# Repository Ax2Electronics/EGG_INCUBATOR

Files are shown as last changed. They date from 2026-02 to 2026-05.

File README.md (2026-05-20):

# EGG_INCUBATOR
Egg Incubator Chamber With Custom Made Modern Controller Interface, quality and accuracy oriented.

BLOCK DIAGRAM of Incubation Controller
PDF: [INCUBATION_CONTROLLER_BD_V7.pdf](https://github.com/user-attachments/files/28039047/INCUBATION_CONTROLLER_BD_V7.pdf)



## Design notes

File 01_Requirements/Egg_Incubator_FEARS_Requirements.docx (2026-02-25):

PRODUCT REQUIREMENTS SPECIFICATION

Chicken Egg Incubator Controller | FEARS Format | Version 1.0 | DRAFT

Document Title | Product Requirements Specification – Chicken Egg Incubator Controller
Product | Fully Automatic Egg Incubator (up to 100 eggs)
Format | FEARS (Functional / Electrical & Environmental / Appearance & Aesthetic / Regulatory & Reliability / Safety & Standards)
Target Market | Balkan Region (Serbia primary) and EU
Document Version | 1.0 – Draft for Review
Date | 25 February 2026
Prepared By | Requirements Engineering Team (Electronics, Firmware, Mechanical, Regulatory)
Status | DRAFT – Pending technical and regulatory review

# 1. Introduction & Scope

This document defines the complete product requirements for a Fully Automatic Chicken Egg Incubator Controller in FEARS format. Requirements cover the full product lifecycle from manufacturing, first use, normal operation, edge and misuse conditions, maintenance, and end-of-life decommissioning. All requirements are written to support CE marking for the EU market and Serbian market compliance.

Priority notation: Must = mandatory requirement; Should = strongly recommended; May = optional / nice to have.

# F | FUNCTIONAL REQUIREMENTS

ID | Sub-System / Feature | Requirement Statement | Priority | Use Case / Context
F-001 | Temperature Control | The system SHALL maintain egg chamber temperature in range 37.0°C – 39.0°C with a steady-state accuracy of ±0.1°C. | Must | Normal, First Use
F-002 | Temperature Sensing | The system SHALL use a minimum of 2 independent temperature sensors (NTC/PT100) with cross-validation. If sensors disagree by >0.5°C, alarm shall be raised. | Must | Normal, Fault
F-003 | Humidity Control | The system SHALL control relative humidity (RH) in the range 40%–80% RH ±3% RH via automatic water dispensing from external tank. | Must | Normal
F-004 | Humidity Sensing | The system SHALL measure humidity using a digital RH/T sensor (e.g., SHT3x class). Sensor shall be recalibrated or cross-checked at each power-on. | Must | Normal, Startup
F-005 | Water Level Monitoring | The system SHALL monitor the water tank level. An alert SHALL be displayed and audible alarm triggered when tank drops below minimum level. | Must | Normal, Depletion
F-006 | Fan Operation | The system SHALL operate an internal circulation fan continuously during incubation to ensure uniform temperature distribution (≤±0.3°C variation chamber-wide). | Must | Normal
F-007 | Fan Fault Detection | The system SHALL detect fan failure (stall or over-current) within 30 seconds and raise an audible + visual alarm. | Must | Fault
F-008 | Egg Turning – Auto | The system SHALL automatically turn eggs at configurable intervals (default: every 2h ±5 min) through the turning mechanism, stopping 3 days before projected hatch. | Must | Normal
F-009 | Egg Turning – Manual Override | The operator SHALL be able to manually trigger an egg turn from the touchscreen at any time outside the lockdown period. | Should | Manual Operation
F-010 | Lockdown Mode | The system SHALL enter a 'Lockdown' mode in the last 3 days of incubation, stopping egg turning and adjusting humidity to 65%–70% RH automatically. | Must | Hatch Phase
F-011 | Incubation Timer | The system SHALL track incubation day count from a user-set start date. Countdown to expected hatch date shall be displayed. | Must | Normal
F-012 | LED Lighting | The system SHALL provide internal LED illumination, controllable via touchscreen (ON/OFF + brightness). LED SHALL automatically extinguish when door is opened. | Must | Normal, Door Open
F-013 | Touchscreen Display | The system SHALL present real-time readings (temperature, humidity, fan status, water level, incubation day, alarms) on an LCD touchscreen ≥3.5 inches diagonal. | Must | Normal
F-014 | Alarm System | The system SHALL provide audible (≥70 dB @ 1m) and visual alarms for: high/low temperature, high/low humidity, fan failure, water low, power failure, sensor fault. | Must | Fault, Emergency
F-015 | Alarm Mute / Acknowledge | The user SHALL be able to acknowledge/mute alarms via touchscreen. Alarm condition shall be logged even if muted. Mute SHALL auto-expire after 60 minutes. | Must | Fault
F-016 | Power Failure Handling | Upon power loss, the system SHALL retain all settings, alarm history, and incubation timer data in non-volatile memory (EEPROM/Flash). Upon restore, it SHALL resume operation automatically. | Must | Power Failure
F-017 | Configurable Parameters | The operator SHALL be able to set target temperature, target humidity, turning interval, incubation duration, and alarm thresholds via the touchscreen menu. | Must | Setup
F-018 | Factory Default Reset | The system SHALL provide a factory default reset function, accessible only through a multi-step confirmation on the touchscreen to prevent accidental reset. | Must | Setup, Edge Case
F-019 | Heater Safety Cutoff | The system SHALL automatically disable all heaters if measured temperature exceeds 41.0°C (hard safety limit), regardless of software state. | Must | Safety, Fault
F-020 | Self-Test on Power-Up | On each power-up, the system SHALL perform a self-test of sensors, heater, fan, and display, reporting results to the user before entering normal operation. | Must | Startup
F-021 | Data Logging | The system SHOULD log temperature, humidity, alarm events and operator actions with timestamp, accessible via touchscreen log view (minimum 30-day retention). | Should | Normal, Audit
F-022 | Child/Tamper Lock | The system SHALL provide a touchscreen lock function to prevent unintended parameter changes during active incubation. | Should | Edge Case, Misuse Prevention
F-023 | Egg Capacity Indication | The system SHALL support up to 100 chicken eggs. Firmware SHALL NOT constrain egg count but documentation shall state maximum safe load. | Must | Normal
F-024 | Language Support | The HMI (touchscreen) SHALL support at minimum English, Serbian, Croatian, and Romanian language settings. | Should | Balkan Market
F-025 | Firmware Update | The system SHOULD support secure firmware updates via USB or SD card with integrity verification (CRC/hash check) and rollback capability. | Should | Lifecycle, Maintenance

# E | ELECTRICAL & ENVIRONMENTAL REQUIREMENTS

ID | Parameter | Requirement Statement | Priority | Context
E-001 | Supply Voltage | The device SHALL operate from 230V AC ±10%, 50 Hz mains supply (Balkan/EU standard). | Must | Normal
E-002 | Power Consumption | Total system power consumption at full load (all heaters, fan, lights, controls) SHALL not exceed 200W. | Must | Normal
E-003 | Mains Fusing | A suitably rated mains fuse (T2A min) SHALL be installed on the line conductor of the mains input, accessible for user replacement. | Must | Safety
E-004 | Protective Earth | All metallic enclosure parts SHALL be connected to protective earth (PE). Earth continuity resistance SHALL be ≤0.1Ω. | Must | Safety, Regulatory
E-005 | Heater Design | Heating elements SHALL be PTC or nichrome type, rated for ≥50,000 operating hours. Watt density SHALL be chosen to prevent surface temperature exceeding 80°C. | Must | Reliability
E-006 | EMC – Emissions | The device SHALL comply with EN 55032 Class B conducted and radiated emission limits for residential/commercial use. | Must | Regulatory
E-007 | EMC – Immunity | The device SHALL comply with EN 55035 immunity requirements. Critical functions (temperature control, alarms) SHALL remain operational during ESD, EFT/Burst, and surge tests. | Must | Regulatory
E-008 | ESD Protection | All user-accessible interfaces (touchscreen, USB/SD card slot) SHALL be protected with TVS diodes to withstand ±4kV contact / ±8kV air ESD (IEC 61000-4-2 Level 2/3). | Must | Robustness
E-009 | Surge Protection | The mains input SHALL include a MOV-based surge protector capable of absorbing 1kV/2kV differential/common mode surges per IEC 61000-4-5. | Must | Robustness
E-010 | Operating Temperature (Electronics) | All electronic components SHALL be rated for continuous operation at ambient temperatures of 0°C to +50°C. | Must | Environmental
E-011 | Storage Temperature | The device SHALL withstand storage at -20°C to +70°C without permanent damage (non-operational). | Must | Lifecycle
E-012 | Humidity (Electronics) | Electronics SHALL be protected against condensation. PCBs SHALL be conformally coated or adequately enclosed. Operating RH for electronics: 20% – 85% non-condensing. | Must | Environmental
E-013 | Ingress Protection – Water System | Components in contact with water (humidity system, tank sensors) SHALL be rated IP54 minimum. Main electronics enclosure: IP22 minimum. | Must | Safety, Environmental
E-014 | Insulation Resistance | Insulation resistance between mains-live conductors and accessible parts SHALL be ≥2MΩ at 500V DC under dry conditions. | Must | Safety
E-015 | Dielectric Strength | The device SHALL withstand a 1500V AC dielectric strength test between primary and secondary circuits for 1 minute without breakdown. | Must | Safety, Regulatory
E-016 | Leakage Current | Touch current (leakage) SHALL not exceed 0.5mA (Class I device, EN 60335 criteria). | Must | Safety
E-017 | Low-Voltage Supply (Internal) | Internal SMPS shall provide galvanically isolated 5V/12V/24V DC rails. Isolation SHALL meet reinforced insulation requirements per IEC 62368 or EN 60335. | Must | Safety
E-018 | Over-Temperature Protection (Heater PCB) | A hardware independent thermal fuse (one-shot, ≤105°C trip) SHALL be physically mounted on or near each heating element as last-resort protection. | Must | Safety
E-019 | Watchdog Timer | Firmware SHALL implement a hardware watchdog timer (≤1s timeout) to recover from software lockup. Safety-critical outputs (heaters) SHALL default to OFF on watchdog reset. | Must | Safety, Reliability
E-020 | Battery Backup (RTC) | A coin cell battery SHALL maintain the real-time clock and incubation timer for a minimum of 5 years (device unused). | Must | Reliability
E-021 | Motor Driver Protection | The egg-turning motor driver SHALL include overcurrent protection, stall detection, and soft-start to prevent mechanical and electrical damage. | Must | Reliability

# A | APPEARANCE & AESTHETIC REQUIREMENTS

ID | Sub-System / Feature | Requirement Statement | Priority | Use Case / Context
A-001 | Enclosure Material | The main enclosure SHALL be constructed from ABS or similar food-safe, non-toxic plastic, resistant to cleaning agents (IPA, dilute bleach). | Must | Lifecycle, Safety
A-002 | Colour and Finish | The exterior SHALL use neutral, easy-to-clean colour (white, light grey or beige). Surface finish shall be matte or satin to minimise fingerprint visibility. | Must | Aesthetics
A-003 | Display Visibility | The LCD touchscreen SHALL be readable in ambient light conditions of 100–1000 lux. Minimum display contrast ratio: 300:1. Text size on main screen ≥ 14pt equivalent. | Must | Usability
A-004 | Viewing Window | The incubation chamber SHALL include a transparent polycarbonate or tempered glass viewing window enabling egg observation without opening the lid. | Must | Usability, Aesthetics
A-005 | LED Colour Temperature | Internal LED illumination SHALL be 5000K–6500K (daylight) for accurate egg candling observation. | Should | Function, Aesthetics
A-006 | Touchscreen Bezel | The touchscreen shall have a smooth, sealed bezel (no gaps >0.5mm) to prevent ingress of debris and facilitate cleaning. | Must | Hygiene, Robustness
A-007 | Cable Management | External cables (power cord, water tube) SHALL be routed via designated strain-relief fittings. No loose wiring shall be accessible to the user. | Must | Safety, Aesthetics
A-008 | Controls Intuitiveness | The touchscreen UI SHALL require no more than 3 taps to reach any monitoring screen from the home screen. Icons SHALL be internationally recognisable. | Must | Usability
A-009 | Door / Lid Design | The lid/door mechanism SHALL include a positive latch that requires deliberate action to open, preventing accidental opening during incubation. | Must | Usability, Safety
A-010 | Label and Markings | All external labels SHALL be printed in UV-resistant inks or engraved. Labels SHALL remain legible for the full 10-year design life. | Must | Lifecycle, Regulatory
A-011 | Product Dimensions | The product footprint SHALL accommodate up to 100 eggs in a standard tray configuration. Approximate target size: 600mm × 450mm × 350mm (W×D×H) ±15%. | Should | Function
A-012 | Weight | The device fully loaded (eggs, water) SHALL not exceed 25kg to enable single-person handling. | Should | Ergonomics
A-013 | Feet / Levelling | The device SHALL be equipped with 4 non-slip rubber feet. Levelling feet (adjustable) SHOULD be included to ensure horizontal placement. | Must | Function, Safety
A-014 | Brand and Regulatory Markings | The product SHALL bear: CE mark, UKCA (if applicable), manufacturer logo, model number, mains rating, production date code, and WEEE symbol – all on the rear label. | Must | Regulatory

# R | REGULATORY & RELIABILITY REQUIREMENTS

ID | Sub-System / Feature | Requirement Statement | Priority | Use Case / Context
R-001 | CE Marking | The product SHALL comply with all applicable EU Directives and bear CE marking prior to placing on the EU/EEA market (LVD, EMC, RoHS). | Must | Regulatory, Market
R-002 | Low Voltage Directive (LVD) | Compliance with EU Directive 2014/35/EU is required. Essential safety requirements per EN 60335-1 and EN 60335-2 (household appliances) shall be met. | Must | Regulatory
R-003 | EMC Directive | Compliance with EU Directive 2014/30/EU. EMC test reports shall be retained in the Technical File. | Must | Regulatory
R-004 | RoHS Directive | All materials and components SHALL comply with EU RoHS 3 (Directive 2015/863/EU). Lead-free solder SHALL be used throughout. | Must | Regulatory, Environment
R-005 | WEEE Directive | The product SHALL be registered under the WEEE Directive (2012/19/EU). WEEE symbol shall be marked on product. Take-back scheme must be in place for EU market. | Must | Regulatory, EOL
R-006 | REACH Regulation | All substances of very high concern (SVHCs) in the product at >0.1% w/w shall be disclosed per REACH (EC No 1907/2006). | Must | Regulatory
R-007 | Serbian Market (SRPS) | For the Serbian market, the product SHALL comply with applicable SRPS standards and be notified to the relevant authority. CE-equivalent declaration shall be prepared for Serbian authorities. | Must | Regulatory, Market
R-008 | Technical Documentation | A complete Technical File (DoC, risk assessment, test reports, schematics, BoM, user manual) SHALL be compiled and retained for 10 years post last manufacture date. | Must | Regulatory
R-009 | MTBF Target | The system MTBF SHALL be ≥20,000 hours under normal operating conditions (continuous operation, 37.8°C ambient chamber, 30°C external ambient). | Must | Reliability
R-010 | Design Life | The product SHALL be designed for a minimum 10-year operational life with scheduled maintenance (cleaning, filter replacement) every 12 months. | Must | Reliability, Lifecycle
R-011 | Heater Element Life | Heating elements SHALL be rated for ≥50,000 hours continuous duty or be designed as a replaceable field-serviceable module. | Must | Reliability
R-012 | Fan Bearing Life | The circulation fan SHALL use sealed ball bearings rated for ≥30,000 hours MTBF. | Must | Reliability
R-013 | Touchscreen Durability | The touchscreen SHALL be rated for ≥500,000 touch activations before failure. | Should | Reliability
R-014 | Corrosion Resistance | All metallic fasteners and internal hardware SHALL be stainless steel (A2/304) or zinc-plated steel to resist corrosion from humid environment. | Must | Reliability, Lifecycle
R-015 | Seal Degradation | Door gaskets and water system seals SHALL be silicone-based, resistant to temperature cycling (-20°C to +60°C), and rated for ≥10,000 open/close cycles. | Must | Reliability
R-016 | Spare Parts Availability | The manufacturer SHALL commit to spare parts availability (fan, heater, humidity sensor, gaskets, control PCB) for a minimum of 7 years after end of production. | Must | Lifecycle, Service
R-017 | Calibration | The temperature measurement chain SHALL be factory-calibrated and traceable to national standards. Calibration certificate SHALL be provided in the product documentation. | Must | Regulatory, Quality
R-018 | Packaging | Product packaging SHALL comply with EU Packaging Directive (94/62/EC as amended). Packaging materials shall be recyclable and marked accordingly. | Should | Regulatory, Environment

# S | SAFETY & STANDARDS REQUIREMENTS

ID | Sub-System / Feature | Requirement Statement | Priority | Use Case / Context
S-001 | Electrical Safety Standard | The device SHALL be designed and tested in accordance with EN 60335-1:2020 (General requirements for household electrical appliances) and applicable Part 2. | Must | Regulatory, Safety
S-002 | Overheat Protection – Hardware | A hardware-independent thermal cutout (auto-reset thermostat ≤42°C + one-shot thermal fuse ≤105°C) SHALL be fitted in the heater circuit, independent of the microcontroller. | Must | Safety
S-003 | Overheat Protection – Software | Firmware SHALL implement an independent high-temperature alarm and heater shut-off at 41.0°C. This shall be a separate software task from the PID control loop. | Must | Safety
S-004 | Runaway Heating Prevention | The system SHALL limit maximum heater duty cycle to prevent thermal runaway. If temperature rises >2°C above setpoint, heater shall immediately disable. | Must | Safety
S-005 | Water Ingress Protection | The water and humidity systems shall be physically and electrically isolated from mains voltage. All water-carrying components shall be located away from mains wiring with a minimum 25mm creepage. | Must | Safety
S-006 | Water Leak Detection | The system SHOULD incorporate a moisture/leak sensor at the base of the enclosure. A water leak SHALL trigger an alarm and disable the water dispensing pump. | Should | Safety
S-007 | Burn Risk – Enclosure | No external surface accessible to the user shall exceed 60°C during normal operation (EN 60335 touch temperature limits for plastic surfaces). | Must | Safety
S-008 | Child Safety | The device is intended for agricultural/hobbyist use by adults. Mains connection, water tank access, and lid opening SHALL require deliberate multi-step actions to mitigate child hazard. Choking hazard parts shall not be accessible. | Must | Safety
S-009 | Ventilation | The device enclosure SHALL provide adequate ventilation for the electronics compartment to prevent overheating. Ventilation openings SHALL be designed to prevent ingress of eggs, debris, or fingers (IP2X for finger probe). | Must | Safety
S-010 | Moving Parts Guard | The egg-turning mechanism and fan shall be guarded so that no user-accessible opening allows finger contact with moving parts (EN 60335 finger probe test). | Must | Safety
S-011 | Power Cord | The mains power cord SHALL be a certified HAR-marked flexible cable ≥H05VV-F 3G1.0mm², minimum 1.5m long, fitted with a CEE 7/7 schuko plug for Balkan/EU markets. | Must | Safety, Regulatory
S-012 | Abnormal Operation | The device SHALL be tested for abnormal conditions per EN 60335-1 Clause 19: blocked ventilation, locked fan, heater short, sensor open/short. No fire, shock, or unsafe emission shall result. | Must | Safety
S-013 | Malicious/Incorrect Use – Overfill | If water tank is overfilled, the system SHALL detect overflow via water level sensor and cease pumping before overflow reaches electronics. | Must | Safety, Misuse
S-014 | Malicious/Incorrect Use – Wrong Voltage | The device SHALL incorporate a mains voltage selector or be rated for 230V ±10% only. Connecting to 110V SHALL not cause damage; connecting to higher voltage SHALL be mitigated by MOV/fuse protection. | Should | Safety, Misuse
S-015 | Malicious Firmware | Firmware update procedure SHALL validate image authenticity (CRC + signing) before flashing. Unsigned or corrupted firmware SHALL be rejected and current firmware retained. | Must | Security, Misuse
S-016 | Single Fault Safety | Under any single electrical fault (short circuit, open circuit, component failure), the device SHALL not present a risk of fire, electric shock, or dangerous temperature. | Must | Safety
S-017 | Humidity Chemical Safety | The water used for humidity generation SHALL be plain water only. Product documentation SHALL explicitly prohibit use of chemicals or additives in the water tank. | Must | Safety
S-018 | Biological Decontamination | The enclosure interior and accessible surfaces SHALL be designed to withstand decontamination with 70% IPA or 1% sodium hypochlorite solution without material degradation. | Must | Hygiene, Lifecycle
S-019 | End-of-Life Disposal | The product SHALL be labelled with WEEE symbol. User documentation SHALL provide instructions for safe disposal and identify components requiring special handling (battery, PCB). | Must | Regulatory, EOL
S-020 | Electromagnetic Compatibility – Safety Devices | Alarm circuits and safety cutouts SHALL be immune to EMI and shall function correctly even during worst-case EMC test conditions. | Must | Safety, Regulatory
S-021 | Shipping / Drop Safety | The unit (packaged) SHALL survive a 0.5m drop onto a concrete surface without permanent functional damage or safety compromise. | Should | Lifecycle

# APPENDIX A | APPLICABLE STANDARDS & DIRECTIVES

The following standards and directives are applicable to this product. Mandatory standards must be demonstrated through testing and/or technical documentation for market access. Recommended standards represent best practice.

Standard / Directive | Title / Scope | Category | Status
EN 60335-1:2020 + A11:2022 | Safety of household and similar electrical appliances – Part 1: General requirements | Safety | Mandatory (LVD)
EN 60335-2-101 | Safety – Part 2-101: Particular requirements for vaporisers (humidity) | Safety | Applicable
IEC 62368-1:2018 (EN 62368-1) | Audio/video, IT and comms – Safety requirements (supersedes EN 60065 / EN 60950) | Safety | Applicable if classified under AV/IT
EN 55032:2015+A1:2020 | Electromagnetic compatibility – Emission requirements for multimedia equipment | EMC | Mandatory (EMC Directive)
EN 55035:2017+A11:2020 | Electromagnetic compatibility – Immunity requirements for multimedia equipment | EMC | Mandatory (EMC Directive)
IEC 61000-4-2:2009 | ESD immunity test | EMC/Immunity | Mandatory
IEC 61000-4-4:2012 | EFT/Burst immunity test | EMC/Immunity | Mandatory
IEC 61000-4-5:2017 | Surge immunity test | EMC/Immunity | Mandatory
IEC 61000-4-11:2020 | Voltage dips and interruptions immunity | EMC/Immunity | Mandatory
EN IEC 61000-3-2:2019+A1:2021 | Harmonic current emissions (≤16A) | EMC | Mandatory
EN 61000-3-3:2013+A1:2019 | Voltage fluctuations and flicker (≤16A) | EMC | Mandatory
EU Directive 2014/35/EU | Low Voltage Directive (LVD) | Regulatory | Mandatory for CE
EU Directive 2014/30/EU | EMC Directive | Regulatory | Mandatory for CE
EU Directive 2011/65/EU + 2015/863/EU | RoHS 3 – Restriction of Hazardous Substances | Regulatory/Environmental | Mandatory
EU Directive 2012/19/EU (WEEE) | Waste Electrical and Electronic Equipment Directive | Regulatory/EOL | Mandatory
EC Regulation 1907/2006 (REACH) | Registration, Evaluation, Authorisation of Chemicals | Regulatory/Environmental | Mandatory
EU Directive 94/62/EC (Packaging) | Packaging and packaging waste | Regulatory/Environmental | Applicable
SRPS EN 60335-1 | Serbian national adoption of EN 60335-1 (safety) | Regulatory – Serbia | Mandatory for Serbian market
SRPS EN 55032 / SRPS EN 55035 | Serbian national adoption of EMC standards | Regulatory – Serbia | Mandatory for Serbian market
EN IEC 63000:2018 | Technical documentation for RoHS compliance assessment | Documentation | Recommended
IEC 60068-2-1/2/14 | Environmental testing – Cold, Dry heat, Temperature change | Environmental/Reliability | Recommended
IEC 60068-2-30 | Environmental testing – Damp heat cyclic | Environmental/Reliability | Recommended
IEC 60529 | Degrees of protection (IP code) – Ingress protection | Safety/Environmental | Mandatory (IP rating claim)
EN ISO 9241-11:2018 | Ergonomics of human-system interaction – Usability | Usability | Recommended
IEC 62133 | Battery safety (if rechargeable battery fitted for backup) | Safety | Applicable if Li-ion used
EN 301 489-1 (if wireless) | EMC for radio equipment – Common technical requirements | EMC/Radio | If wireless functionality added
EN 300 328 (if 2.4GHz WiFi/BT) | Radio equipment – 2.4GHz wideband transmission | Radio/EMC | If wireless functionality added

# APPENDIX B | EDGE CASES & MISUSE SCENARIOS ADDRESSED

The following edge cases, wrong uses, and malicious uses have been explicitly addressed within the requirements above:

Scenario | Risk | Requirement(s) Addressing It
Accidental factory reset | Loss of all incubation settings mid-cycle, potential egg loss | F-018
Power failure mid-incubation | Loss of timer, settings, and temperature control | F-016, E-020
Sensor failure (open/short) | Undetected temperature runaway or incorrect readings | F-002, F-004, F-020, S-012
Fan blockage / stall | Uneven temperature, overheating, egg loss | F-007, E-021
Water tank dry | Humidity collapse, embryo desiccation | F-005
Water tank overfill / leak | Electrical shock hazard, electronics damage | S-005, S-006, S-013
Child access to device | Burn risk, electric shock, ingestion of parts | S-008, S-009, S-010
User pours chemicals into water tank | Chemical vapour inside chamber, health hazard | S-017
Device used at wrong mains voltage | Component damage, fire, shock hazard | S-014, E-009
Malicious or corrupted firmware upload | Loss of safety functions, data exfiltration | F-025, S-015
Door opened accidentally during incubation | Temperature/humidity loss, embryo mortality | A-009, F-012
Unauthorised parameter changes | Temperature/humidity set outside safe range | F-022
Software lockup / crash | Heater left on or fan disabled indefinitely | E-019
Device dropped during installation | Structural and safety failure | S-021
Condensation inside electronics compartment | PCB corrosion, short circuit, shock hazard | E-012, E-013
End of life – improper disposal | Toxic materials entering waste stream | R-005, R-006, S-019
Continued use after thermal fuse trip | User bypasses protection; fire/shock risk | E-018, user documentation, fuse access design

Document End – Requirements Engineering Team

CONFIDENTIAL – Internal Use Only | Requirements Engineering Team | Page {PAGE}

PRODUCT REQUIREMENTS SPECIFICATION | Chicken Egg Incubator Controller | FEARS Format | v1.0 | DRAFT

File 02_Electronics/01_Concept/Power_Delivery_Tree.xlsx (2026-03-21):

 |  | I_IN | 4.264912551 | I_IN | 1.676842593 | I_IN | 1.10198
 | 24V/12V External Voltage Supply |  | DC/DC 12V VOUT |  | DC/DC 5V VOUT |  | DC/DC 3V3 VOUT |  |  |  | MCU STM32F401RE
I [A] | 4.264912551 | I [A] | 7.676842593 | I [A] | 3.62198 | I [A] | 1.5027 |  |  | I [A] | 0.32
V [V] | 24 | V [V] | 12 | V [V] | 5 | V [V] | 3.3 |  |  | V [V] | 3.3
P [W] | 102.3579012 | P [W] | 92.12211111 | P [W] | 18.1099 | P [W] | 4.95891 |  |  | P [W] | 1.056
 |  |  |  |  | 12V DC FAN |  | DC/DC isolated RFM-0505S |  | AMC23C10 |  | RTC MAX31334EWC+T OR MAX31331TETB+
 |  |  |  | I [A] | 0.5 | I [A] | 0.02 | I [A] | 0.01 | I [A] | 0.0007
 |  |  |  | V [V] | 12 | V [V] | 5 | V [V] | 5 | V [V] | 3.3
 |  |  |  | P [W] | 6 | P [W] | 0.1 | P [W] | 0.05 | P [W] | 0.00231
 |  |  |  |  | 12V DC FAN |  | NEXTION 3.5in DISCOVERY DISPLAY |  |  |  | uSD CARD
 |  |  |  | I [A] | 0.5 | I [A] | 0.5 |  |  | I [A] | 0.3
 |  |  |  | V [V] | 12 | V [V] | 5 |  |  | V [V] | 3.3
 |  |  |  | P [W] | 6 | P [W] | 2.5 |  |  | P [W] | 0.99
 |  |  |  |  | NEMA17 Stepper Motor |  | SERVO - egg tray LOCK Mechanism Option x4 |  |  |  | Temperature Sensor DS18B20
 |  |  |  | I [A] | 2 | I [A] | 2 |  |  | I [A] | 0.002
 |  |  |  | V [V] | 12 | V [V] | 5 |  |  | V [V] | 3.3
 |  |  |  | P [W] | 24 | P [W] | 10 |  |  | P [W] | 0.0066
 |  |  |  |  | 12V Electromagnetic Valve |  |  |  |  |  | Temperature&Humidity Sensor SHT40
 |  |  |  | I [A] | 1 |  |  |  |  | I [A] | 0.2
 |  |  |  | V [V] | 12 |  |  |  |  | V [V] | 3.3
 |  |  |  | P [W] | 12 |  |  |  |  | P [W] | 0.66
 |  |  |  |  | 12V Electromagnetic Valve |  |  |  |  |  | Water level sensor x2
 |  |  |  | I [A] | 1 |  |  |  |  | I [A] | 0.1
 |  |  |  | V [V] | 12 |  |  |  |  | V [V] | 3.3
 |  |  |  | P [W] | 12 |  |  |  |  | P [W] | 0.33
 |  |  |  |  | 12V LED Strip |  |  |  |  |  | Door open sensor
 |  |  |  | I [A] | 1 |  |  |  |  | I [A] | 0
 |  |  |  | V [V] | 12 |  |  |  |  | V [V] | 0
 |  |  |  | P [W] | 12 |  |  |  |  | P [W] | 0
 |  |  |  |  |  |  |  |  |  |  | WiFi ESP32
 |  |  |  |  |  |  |  |  |  | I [A] | 0.5
 |  |  |  |  |  |  |  |  |  | V [V] | 3.3
 |  |  |  |  |  |  |  |  |  | P [W] | 1.65
 |  |  |  |  |  |  |  |  |  |  | STEPPER DRIVER DRV8462 DRV8461 DRV8452
 |  |  |  |  |  |  |  |  |  | I [A] | 0.01
 |  |  |  |  |  |  |  |  |  | V [V] | 3.3
 |  |  |  |  |  |  |  |  |  | P [W] | 0.033
 |  |  |  |  |  |  |  |  |  |  | MOC3061 + triac
 |  |  |  |  |  |  |  |  |  | I [A] | 0.05
 |  |  |  |  |  |  |  |  |  | V [V] | 3.3
 |  |  |  |  |  |  |  |  |  | P [W] | 0.165
 |  |  |  |  |  |  |  |  |  |  | AMC23C10
 |  |  |  |  |  |  |  |  |  | I [A] | 0.01
 |  |  |  |  |  |  |  |  |  | V [V] | 3.3
 |  |  |  |  |  |  |  |  |  | P [W] | 0.033
 |  |  |  |  |  |  |  |  |  |  | MOC3051M + triac
 |  |  |  |  |  |  |  |  |  | I [A] | 0.01
 |  |  |  |  |  |  |  |  |  | V [V] | 3.3
 |  |  |  |  |  |  |  |  |  | P [W] | 0.033
 |  |  |  |  |  |  |  |  |  |  | Voltage Supervisor TPS3842
 |  |  |  |  |  |  |  |  |  | I [A] | 0
 |  |  |  |  |  |  |  |  |  | V [V] | 0
 |  |  |  |  |  |  |  |  |  | P [W] | 0

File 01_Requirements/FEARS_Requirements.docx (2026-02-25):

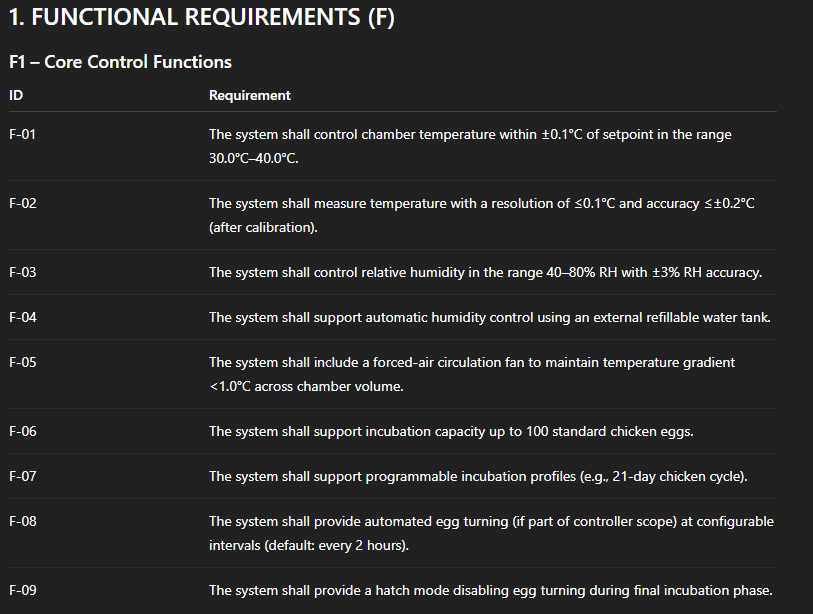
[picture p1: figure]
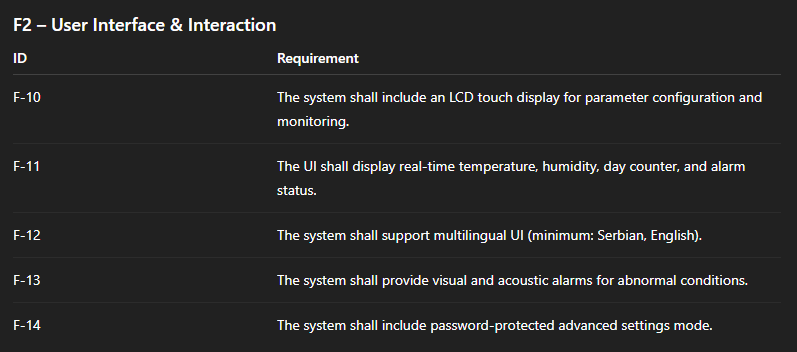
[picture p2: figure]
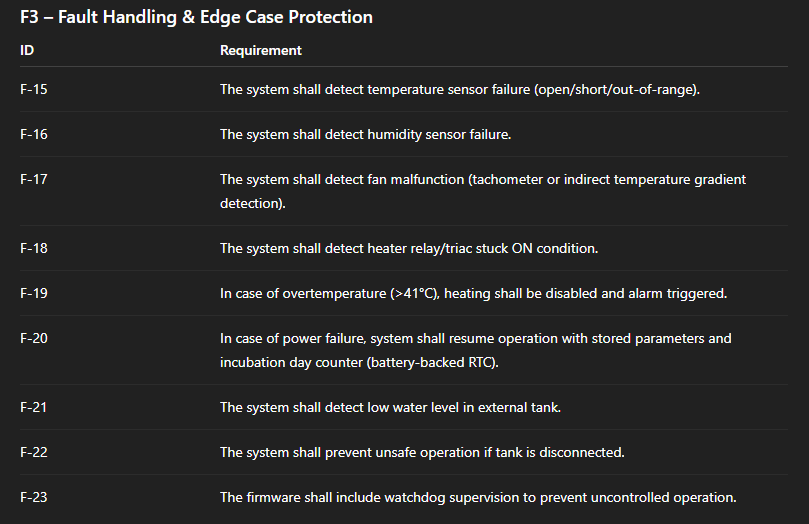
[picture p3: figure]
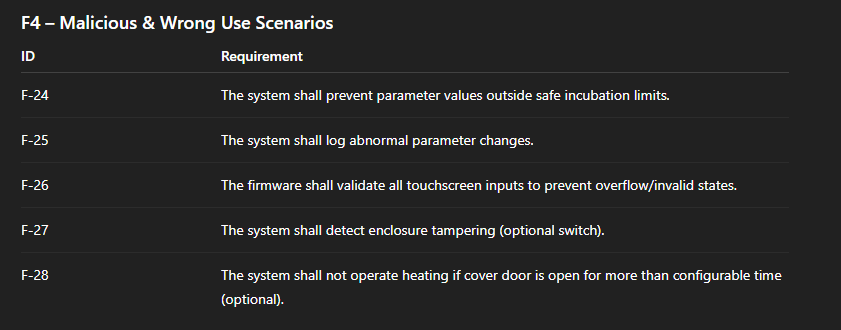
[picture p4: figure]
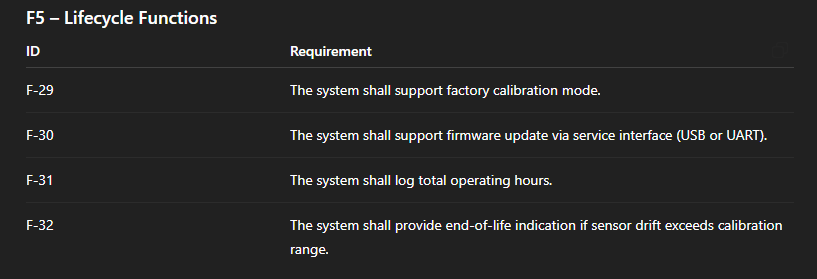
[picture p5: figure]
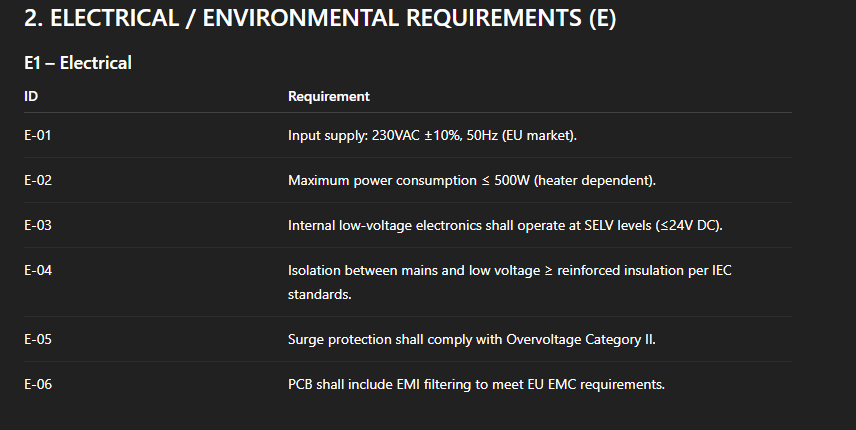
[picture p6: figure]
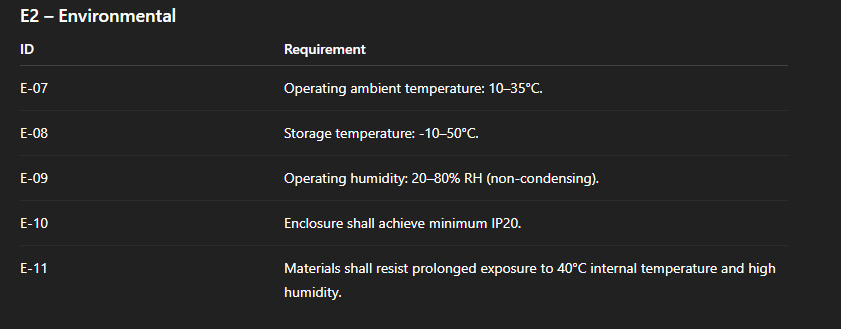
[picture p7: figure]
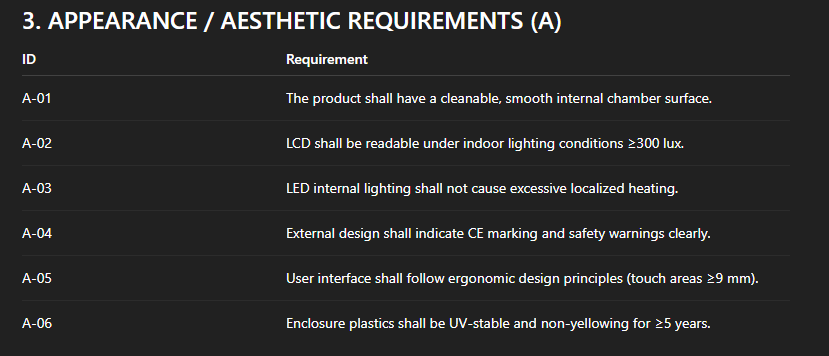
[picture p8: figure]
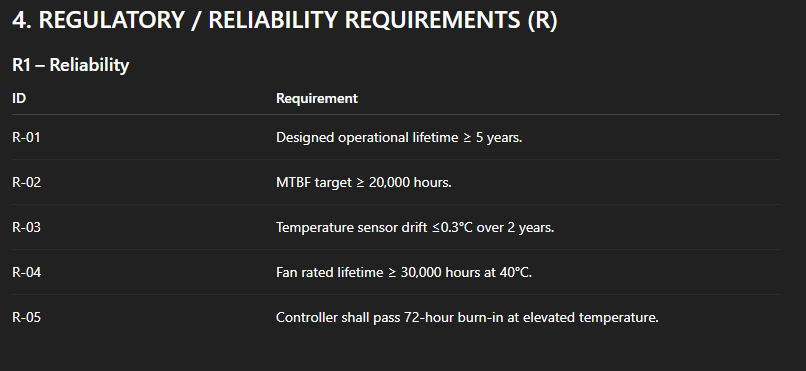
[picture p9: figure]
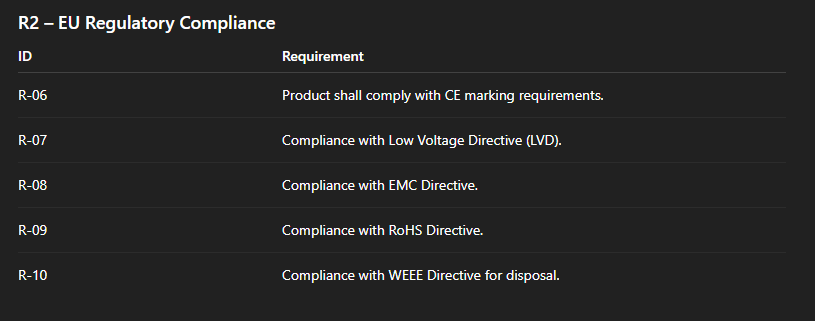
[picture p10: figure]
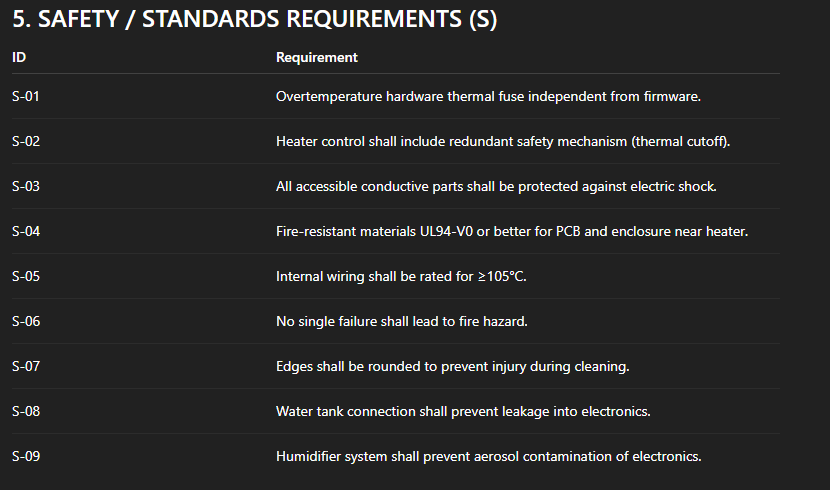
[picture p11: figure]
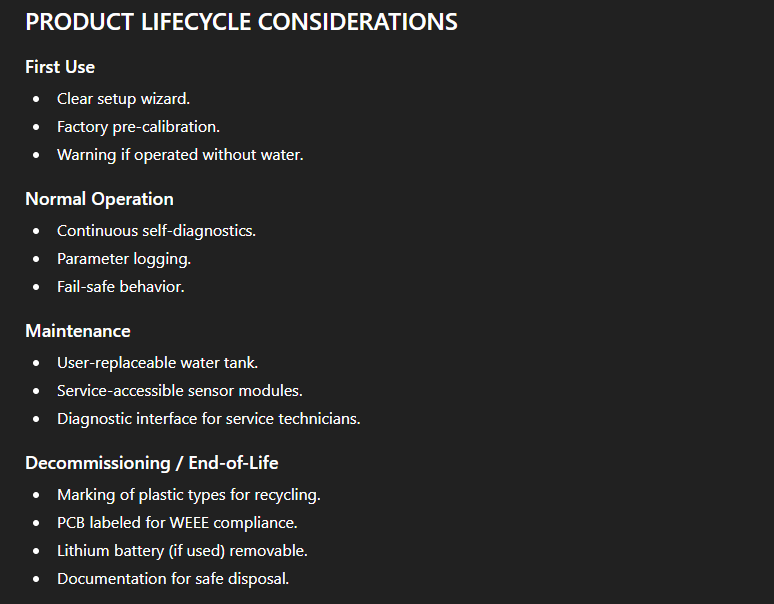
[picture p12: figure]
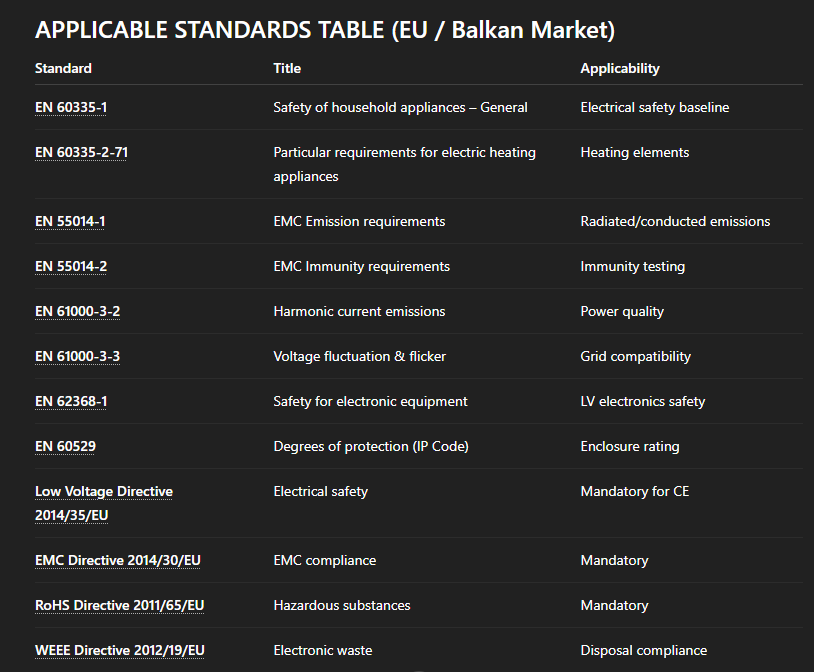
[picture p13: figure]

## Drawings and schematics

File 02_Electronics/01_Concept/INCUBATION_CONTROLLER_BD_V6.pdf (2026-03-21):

# 24V or 12V EXTERNAL - 150W

# 230V EXTERNAL

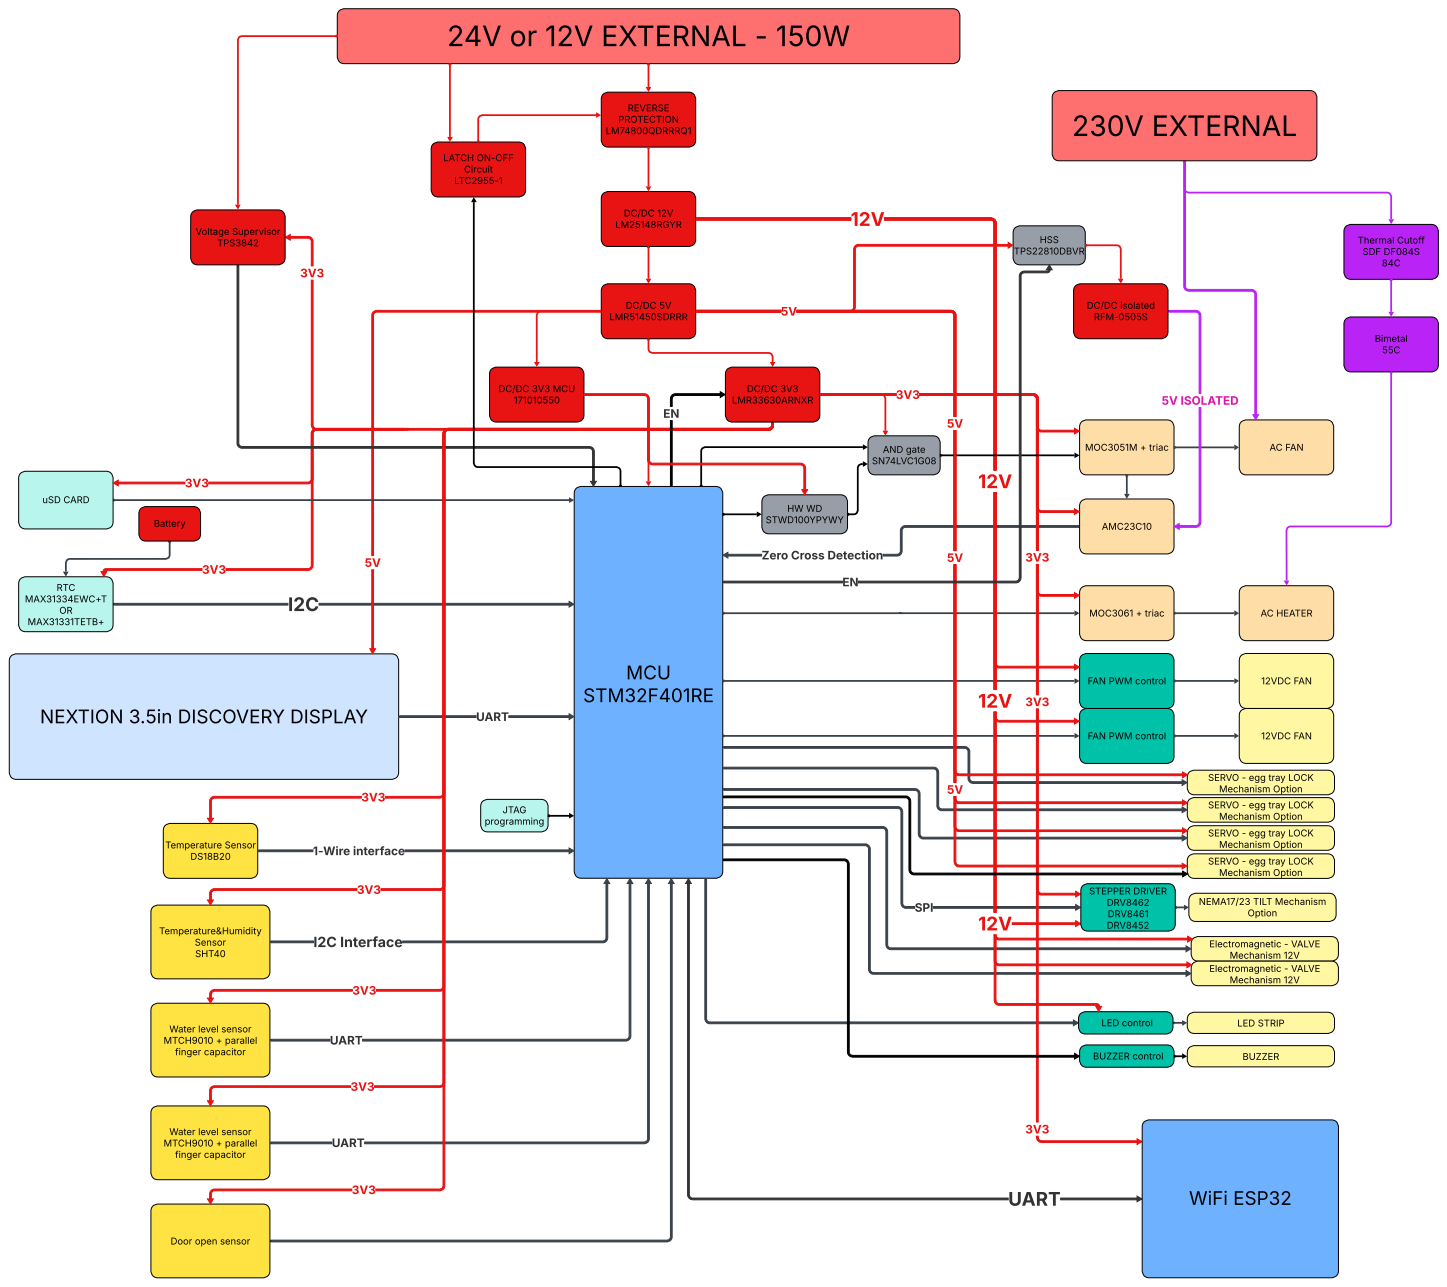
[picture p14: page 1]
AMC23C10; MOC3051M + triac; AC FAN; DC/DC 5V LMR51450SDRRR; MOC3061+ triac; AC HEATER; 5V ISOLATED; MCU STM32F401RE; Temperature Sensor; 1-Wire interface; Temperature&Humidity Sensor SHT40; I2C Interface; RTC MAX31334EWC+T OR MAX31331TETB+; Battery; NEXTION 3.5in DISCOVERY DISPLAY; UART; 12VDC FAN; NEMA17/23 TILT Mechanism Option; Electromagnetic - VALVE Mechanism 12V Electromagnetic - VALVE Mechanism 12V; LED STRIP; SPI; uSD CARD; Thermal Cutoff SDF DF084S 84C; Bimetal 55C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

DC/DC isolated
RFM-0505S

DC/DC 3V3 MCU

Zero Cross Detection

FAN PWM control

SERVO - egg tray LOCK
Mechanism Option

Water level sensor
MTCH9010 + parallel
finger capacitor

Door open sensor (https://www.kupujemprodajem.com/elektronika-i-komponente/moduli-za-samoizgradnju/magnetni-senzor-za-vrata-i-prozore-v2/oglas/136794507)

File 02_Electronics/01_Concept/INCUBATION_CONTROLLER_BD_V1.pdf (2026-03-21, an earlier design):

# 24V or 12V EXTERNAL

# 230V EXTERNAL

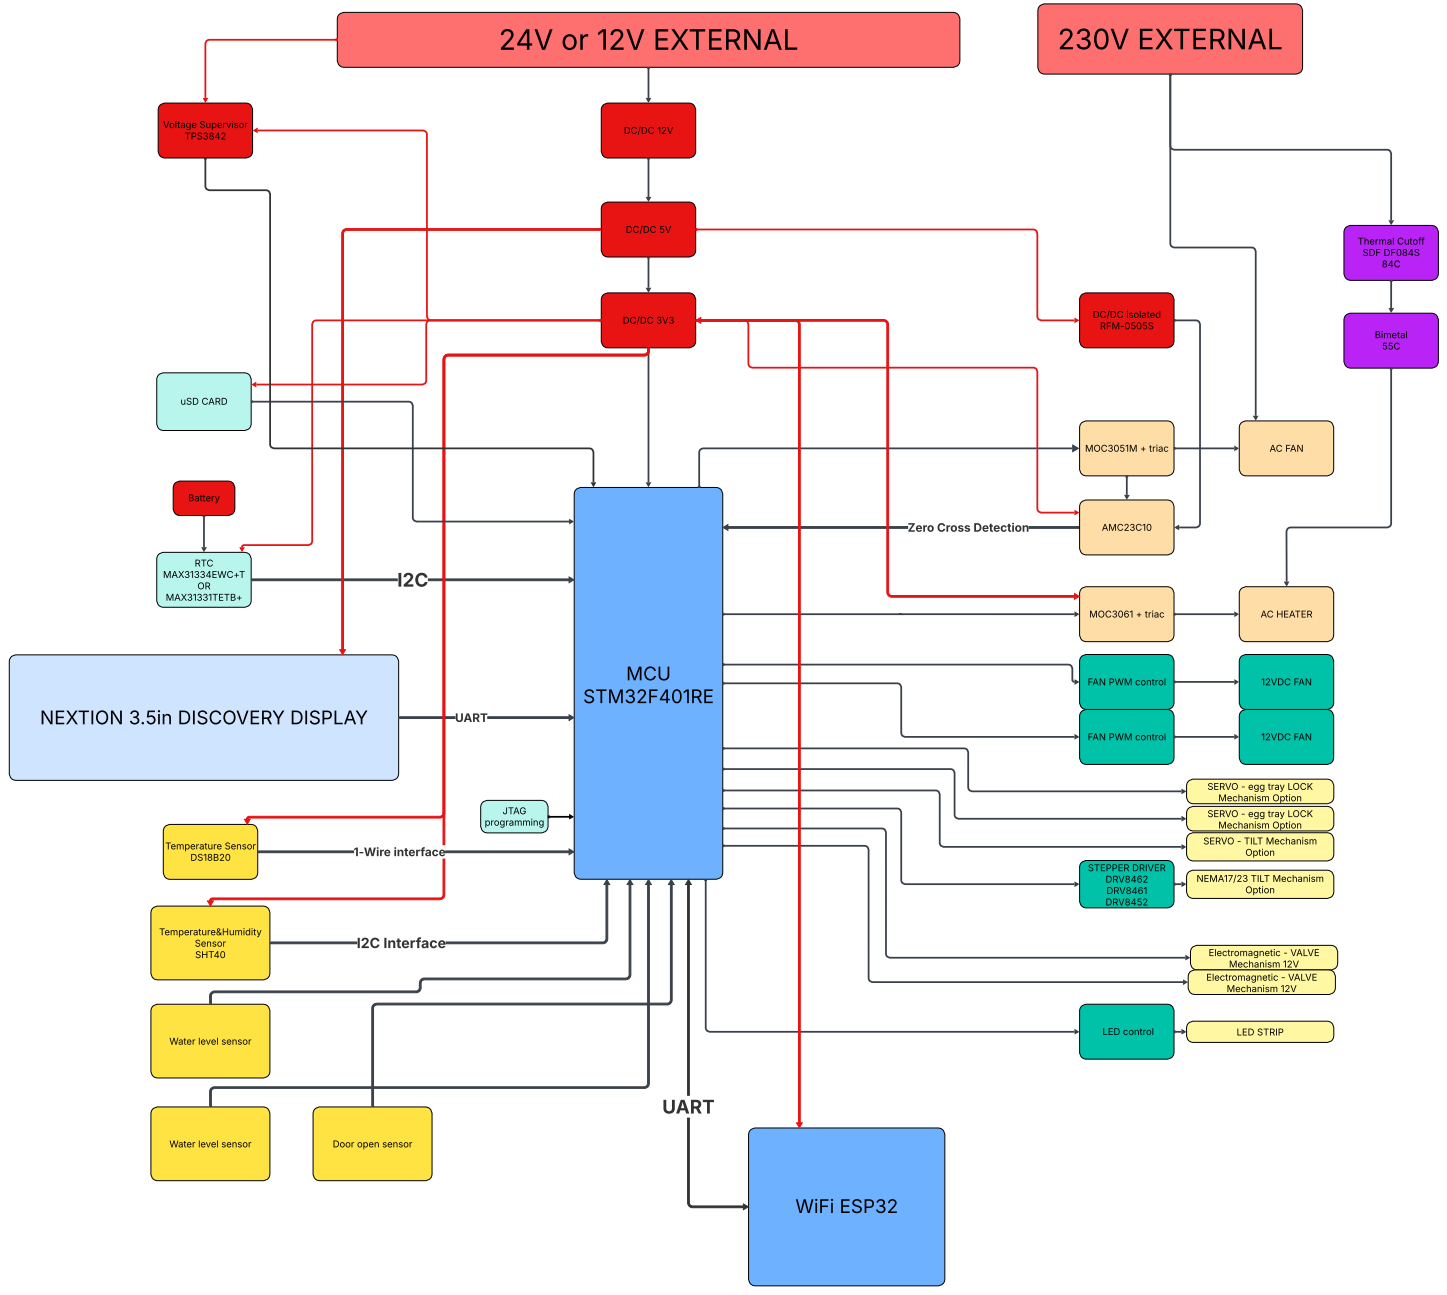
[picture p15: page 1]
AMC23C10; MOC3051M + triac; AC FAN; MOC3061+ triac; AC HEATER; MCU STM32F401RE; Temperature Sensor; 1-Wire interface; Temperature&Humidity Sensor SHT40; I2C Interface; RTC MAX31334EWC+T OR MAX31331TETB+; Battery; NEXTION 3.5in DISCOVERY DISPLAY; UART; FAN PWM control; 12VDC FAN; Option; NEMA17/23 TILT Mechanism Option; STEPPER DRIVER DRV8462 DRV8461 DRV8452; Electromagnetic - VALVE Mechanism 12V Electromagnetic - VALVE Mechanism 12V; LED control; LED STRIP; Thermal Cutoff SDF DF084S 84C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

DC/DC isolated
RFM-0505S

Zero Cross Detection

SERVO - egg tray LOCK
Mechanism Option
SERVO - TILT Mechanism

Water level sensor

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

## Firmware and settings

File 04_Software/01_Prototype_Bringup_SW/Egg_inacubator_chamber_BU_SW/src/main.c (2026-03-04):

#include "stm32f4xx_hal.h"
#include "tim.h"
#include "servo.h"

static void SystemClock_Config(void);

int main(void) {
    HAL_Init();
    SystemClock_Config();

    /* Inicijalizacija periferija */
    TIM3_PWM_Init();
    Servo_Init();

    /* Potvrdi poziciju pri startu */
    Servo_SetAngle(TRAY_CENTER);
    HAL_Delay(3000u);
    Servo_SetAngle(TRAY_LEFT);
    HAL_Delay(3000u);
    Servo_SetAngle(TRAY_RIGHT);
    HAL_Delay(3000u);

    /* Pokreni prvo okretanje — levo */
    //Servo_StartMoveTo(TRAY_LEFT);
    //Servo_DemoSequence();
    /* Superloop */
    uint32_t now = 0u;

    while (1) {
        now = HAL_GetTick();

        /* Servo non-blocking update — mora biti svaki ciklus */
        Servo_Update(now);
    // Zadaj novo kretanje samo kada je servo slobodan
    if (!Servo_IsBusy()) {
        if (Servo_GetAngle() == TRAY_LEFT) {
            Servo_StartMoveTo(TRAY_RIGHT);
        } else {
            Servo_StartMoveTo(TRAY_LEFT);
        }
    }
        /* ------------------------------------------------
         * Ovde ce ici ostali taskovi:
         *
         * Task_ReadSensors(now);
         * Task_TemperatureControl(now);
         * Task_HumidityControl(now);
         * Task_SafetyCheck(now);
         * Task_EggTurning(now);
         * Task_UpdateDisplay(now);
         * Task_DataLogging(now);
         * Task_AlarmHandler(now);
         * ------------------------------------------------ */
    }
}

static void SystemClock_Config(void) {
    RCC_OscInitTypeDef osc = {0};
    RCC_ClkInitTypeDef clk = {0};

    osc.OscillatorType      = RCC_OSCILLATORTYPE_HSI;
    osc.HSIState            = RCC_HSI_ON;
    osc.HSICalibrationValue = RCC_HSICALIBRATION_DEFAULT;
    osc.PLL.PLLState        = RCC_PLL_ON;
    osc.PLL.PLLSource       = RCC_PLLSOURCE_HSI;
    osc.PLL.PLLM            = 16;
    osc.PLL.PLLN            = 336;
    osc.PLL.PLLP            = RCC_PLLP_DIV4;
    osc.PLL.PLLQ            = 7;
    HAL_RCC_OscConfig(&osc);

    clk.ClockType      = RCC_CLOCKTYPE_SYSCLK | RCC_CLOCKTYPE_HCLK |
                         RCC_CLOCKTYPE_PCLK1  | RCC_CLOCKTYPE_PCLK2;
    clk.SYSCLKSource   = RCC_SYSCLKSOURCE_PLLCLK;
    clk.AHBCLKDivider  = RCC_SYSCLK_DIV1;
    clk.APB1CLKDivider = RCC_HCLK_DIV2;
    clk.APB2CLKDivider = RCC_HCLK_DIV1;
    HAL_RCC_ClockConfig(&clk, FLASH_LATENCY_2);
}

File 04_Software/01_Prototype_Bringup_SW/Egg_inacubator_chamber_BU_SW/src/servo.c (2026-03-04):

/* ============================================================
 *  Incubator Project — Servo Module
 *  MCU    : STM32F401RE
 *  Timer  : TIM3 CH1 → PA6
 *  Servo  : DS3235
 *
 *  Interni ugao se cuva u desetinkama stepena (ddeg)
 *  0.1° rezolucija, public API koristi cele stepene
 *
 *  500us  =    0° =    0 ddeg
 *  1500us =   90° =  900 ddeg
 *  2500us =  180° = 1800 ddeg
 * ============================================================ */

#include "servo.h"
#include "tim.h"

/* ----------------------------------------------------------
 *  Interne promenljive
 *  Sve u desetinkama stepena (ddeg)
 *  Primer: 90.5° = 905 ddeg
 * ---------------------------------------------------------- */
static uint16_t s_currentDdeg = 900u;   /* Pocetna pozicija 90.0° */
static uint16_t s_targetDdeg  = 900u;
static uint32_t s_lastStepMs  = 0u;
static uint8_t  s_moving      = 0u;

/* ----------------------------------------------------------
 *  Interne pomocne funkcije
 * ---------------------------------------------------------- */

/**
 * @brief  Konvertuje desetine stepena u PWM pulse width (us)
 *
 *  Linearno mapiranje:
 *    0 ddeg (0°)   → 500us
 *  1800 ddeg (180°)→ 2500us
 *
 *  Formula: us = 500 + (ddeg * 2000) / 1800
 */
static uint32_t ddegToUs(uint16_t ddeg) {
    if (ddeg > 1800u) ddeg = 1800u;
    return SERVO_MIN_US + ((uint32_t)ddeg * 2000u) / 1800u;
}

/**
 * @brief  Postavi servo na poziciju u desetinkama stepena
 * @param  ddeg  Ugao u ddeg (0–1800)
 */
static void Servo_SetDdeg(uint16_t ddeg) {
    if (ddeg > 1800u) ddeg = 1800u;
    __HAL_TIM_SET_COMPARE(&htim3, TIM_CHANNEL_1, ddegToUs(ddeg));
    s_currentDdeg = ddeg;
}

/* ----------------------------------------------------------
 *  Public API
 * ---------------------------------------------------------- */

/**
 * @brief  Inicijalizuj servo — postavi na centar i sacekaj
 */
void Servo_Init(void) {
    Servo_SetDdeg(900u);   /* 90.0° — tray horizontalno */
    HAL_Delay(500u);
}

/**
 * @brief  Direktno postavi servo na zadani ugao (bez rampe)
 * @param  deg  Ugao u stepenima (0–180)
 */
void Servo_SetAngle(uint8_t deg) {
    if (deg > 180u) deg = 180u;
    Servo_SetDdeg((uint16_t)deg * 10u);
}

/**
 * @brief  Vrati trenutni ugao serva u stepenima
 * @retval Ugao (0–180)
 */
uint8_t Servo_GetAngle(void) {
    return (uint8_t)(s_currentDdeg / 10u);
}

/**
 * @brief  Proveri da li je servo trenutno u pokretu
 * @retval 1 = u pokretu, 0 = slobodan
 */
uint8_t Servo_IsBusy(void) {
    return s_moving;
}

/**
 * @brief  Pokreni non-blocking kretanje ka ciljnom uglu
 * @param  targetDeg  Ciljni ugao u stepenima (0–180)
 */
void Servo_StartMoveTo(uint8_t targetDeg) {
    if (targetDeg > 180u) targetDeg = 180u;

    uint16_t targetDdeg = (uint16_t)targetDeg * 10u;

    /* Vec na ciljanoj poziciji — nema potrebe za kretanjem */
    if (targetDdeg == s_currentDdeg) return;

    s_targetDdeg = targetDdeg;
    s_moving     = 1u;
    s_lastStepMs = HAL_GetTick();
}

/**
 * @brief  Non-blocking servo update
 *         Pozivaj svaki ciklus main loop-a
 *
 *         Svaki poziv pomera servo za SERVO_STEP_DDEG
 *         samo ako je proslo SERVO_STEP_DELAY_MS od zadnjeg koraka.
 *         Ostatak vremena funkcija izlazi odmah bez blokiranja.
 *
 * @param  now  Trenutni HAL_GetTick() timestamp
 * @retval 1 = kretanje zavrseno ili servo miran
 *         0 = kretanje u toku
 */
uint8_t Servo_Update(uint32_t now) {

    /* Servo miran — izadi odmah */
    if (!s_moving) return 1u;

    /* Jos nije vreme za sledeci korak */
    if ((now - s_lastStepMs) < SERVO_STEP_DELAY_MS) return 0u;
    s_lastStepMs = now;

    /* Pomeri jedan korak ka cilju */
    if (s_currentDdeg < s_targetDdeg) {
        /* Kretanje prema vecim uglovima */
        uint16_t next = s_currentDdeg + SERVO_STEP_DDEG;
        Servo_SetDdeg(next > s_targetDdeg ? s_targetDdeg : next);

    } else if (s_currentDdeg > s_targetDdeg) {
        /* Kretanje prema manjim uglovima — zastita od uint underflow */
        if (s_currentDdeg < SERVO_STEP_DDEG) {
            Servo_SetDdeg(0u);
        } else {
            uint16_t next = s_currentDdeg - SERVO_STEP_DDEG;
            Servo_SetDdeg(next < s_targetDdeg ? s_targetDdeg : next);
        }
    }

    /* Proveri da li smo stigli na cilj */
    if (s_currentDdeg == s_targetDdeg) {
        s_moving = 0u;
        return 1u;
    }

    return 0u;
}

/* ----------------------------------------------------------
 *  Precice za tray pozicije
 * ---------------------------------------------------------- */

/** @brief  Nakloni tray levo (-45° od horizontale) */
void Tray_TiltLeft(void) {
    Servo_StartMoveTo(TRAY_LEFT);
}

/** @brief  Nakloni tray desno (+45° od horizontale) */
void Tray_TiltRight(void) {
    Servo_StartMoveTo(TRAY_RIGHT);
}

/** @brief  Vrati tray u horizontalni polozaj */
void Tray_Center(void) {
    Servo_StartMoveTo(TRAY_CENTER);
}

/* ----------------------------------------------------------
 *  Demo sekvenca — SAMO ZA TESTIRANJE
 *  Blokira main loop — ukloni u produkciji
 * ---------------------------------------------------------- */
void Servo_DemoSequence(void) {

    /* Centar */
    Servo_SetAngle(TRAY_CENTER);
    HAL_Delay(2000u);

    /* Polako levo */
    for (int16_t d = (int16_t)(TRAY_CENTER * 10);
                 d >= (int16_t)(TRAY_LEFT * 10);
                 d -= (int16_t)SERVO_STEP_DDEG) {
        Servo_SetDdeg((uint16_t)d);
        HAL_Delay(SERVO_STEP_DELAY_MS);
    }
    HAL_Delay(2000u);

    /* Polako nazad na centar */
    for (int16_t d = (int16_t)(TRAY_LEFT * 10);
                 d <= (int16_t)(TRAY_CENTER * 10);
                 d += (int16_t)SERVO_STEP_DDEG) {
        Servo_SetDdeg((uint16_t)d);
        HAL_Delay(SERVO_STEP_DELAY_MS);
    }
    HAL_Delay(2000u);

    /* Polako desno */
    for (int16_t d = (int16_t)(TRAY_CENTER * 10);
                 d <= (int16_t)(TRAY_RIGHT * 10);
                 d += (int16_t)SERVO_STEP_DDEG) {
        Servo_SetDdeg((uint16_t)d);
        HAL_Delay(SERVO_STEP_DELAY_MS);
    }
    HAL_Delay(2000u);

    /* Polako nazad na centar */
    for (int16_t d = (int16_t)(TRAY_RIGHT * 10);
                 d >= (int16_t)(TRAY_CENTER * 10);
                 d -= (int16_t)SERVO_STEP_DDEG) {
        Servo_SetDdeg((uint16_t)d);
        HAL_Delay(SERVO_STEP_DELAY_MS);
    }
    HAL_Delay(1000u);
}

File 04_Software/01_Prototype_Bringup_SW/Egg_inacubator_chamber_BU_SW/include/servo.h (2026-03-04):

#ifndef SERVO_H
#define SERVO_H

#include "stm32f4xx_hal.h"
#include <stdint.h>

/* ----------------------------------------------------------
 *  Servo pulse width granice (u mikrosekundama = TIM tikovima)
 * ---------------------------------------------------------- */
#define SERVO_MIN_US    500u    /*   0° */
#define SERVO_MID_US   1500u    /*  90° — tray horizontalno */
#define SERVO_MAX_US   2500u    /* 180° */

/* ----------------------------------------------------------
 *  Ugaone pozicije traya
 * ---------------------------------------------------------- */
#define TRAY_LEFT    45u    /* Tray -45° od horizontale */
#define TRAY_CENTER  90u    /* Tray horizontalno        */
#define TRAY_RIGHT  135u    /* Tray +45° od horizontale */

/* ----------------------------------------------------------
 *  Brzina okretanja
 *  400ms po stepenu → 90 stepeni × 400ms ≈ 36 sekundi
 * ---------------------------------------------------------- */
#define SERVO_STEP_DELAY_MS  200u
#define SERVO_STEP_DDEG 5u

/* ----------------------------------------------------------
 *  Public API
 * ---------------------------------------------------------- */

/* Inicijalizacija — pozovi jednom u main() */
void    Servo_Init(void);

/* Direktno postavljanje ugla — trenutno, bez rampe */
void    Servo_SetAngle(uint8_t deg);

/* Trenutni ugao */
uint8_t Servo_GetAngle(void);

/* Non-blocking pokretanje ka ciljnom uglu */
void    Servo_StartMoveTo(uint8_t targetDeg);

/* Non-blocking update — pozivaj svaki ciklus main loop-a */
/* Vraca 1 kada je kretanje zavrseno, 0 dok je u toku     */
uint8_t Servo_Update(uint32_t now);

/* Provera da li je servo trenutno u pokretu */
uint8_t Servo_IsBusy(void);

/* Precice za tray pozicije */
void    Tray_TiltLeft(void);
void    Tray_TiltRight(void);
void    Tray_Center(void);

/* Demo sekvenca za testiranje — blokira main loop */
void    Servo_DemoSequence(void);

#endif /* SERVO_H */

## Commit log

2026-03-04 BringUP SW developement - servo module added
2026-03-21 Electronics folder structure updated
    [INCUBATION_CONTROLLER.PcbDoc, INCUBATION_CONTROLLER.PrjPcb, MAIN.SchDoc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]
2026-03-21 BLOCK diagram finalised, Schematic structure created
    [12V_SUPPLY.SchDoc, 3V3_MCU.SchDoc, 3V3_SUPPLY.SchDoc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]
